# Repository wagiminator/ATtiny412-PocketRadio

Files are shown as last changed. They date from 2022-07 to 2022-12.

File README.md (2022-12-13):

# FM Pocket Radio with RDS
PocketRadio is an ATtiny402/412 controlled FM radio with RDS (RDA5807MP), an integrated audio amplifier (TC8871 or XPT8871), a LiPo battery charger (MCP73831 or TP4054), an OLED display (SSD1306) and three buttons. You can directly connect a protected 3.7V LiPo battery, a 3W / 4Ω speaker and an FM antenna.

- Project Video (YouTube): https://youtu.be/-taygMlm8Ls
- Design Files (EasyEDA): https://easyeda.com/wagiminator/attiny412-pocket-radio
- Review on Megazoid's Hut (YouTube): https://youtu.be/HVwsa0pgvS4

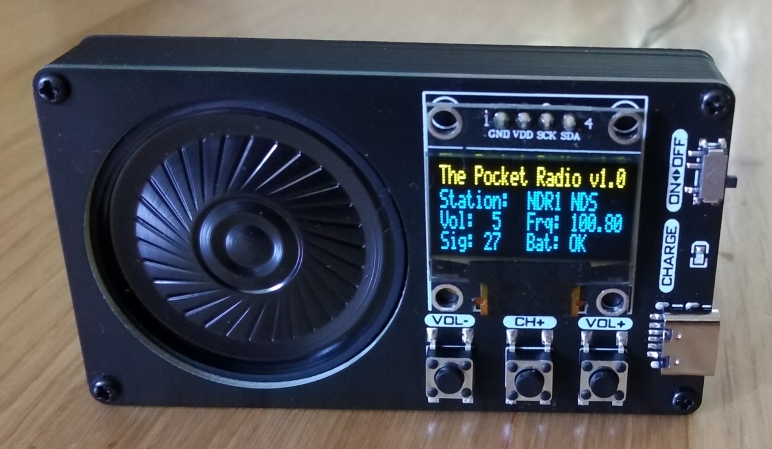
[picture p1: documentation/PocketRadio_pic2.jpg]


# Hardware
## Schematic
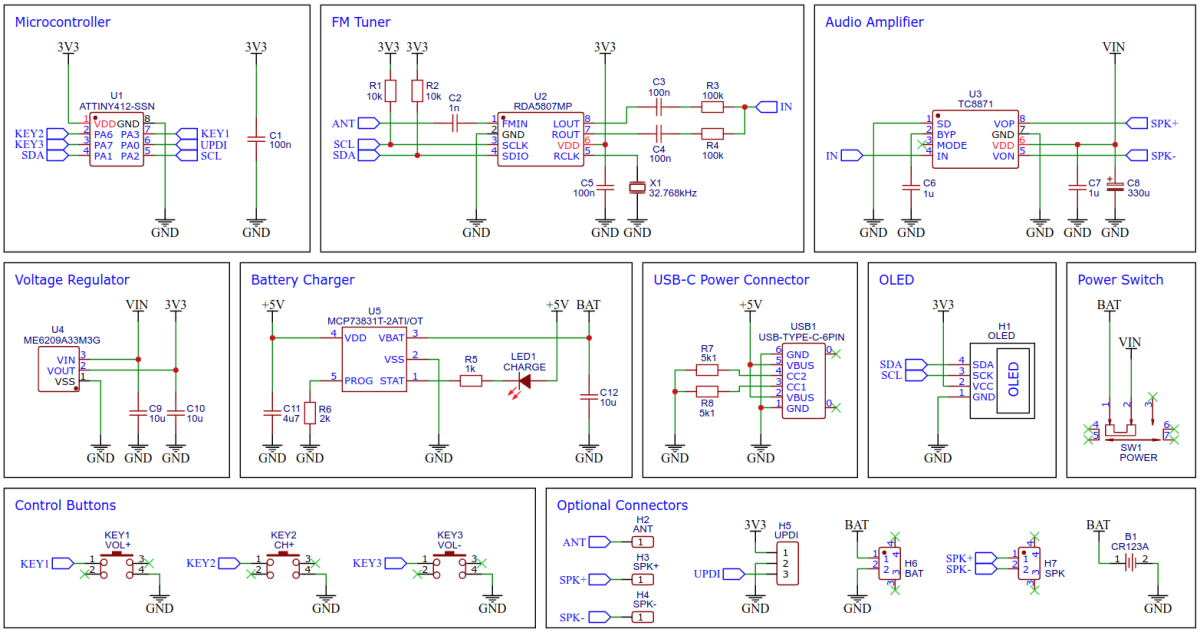
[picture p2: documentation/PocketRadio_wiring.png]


## RDA5807MP FM Radio Tuner IC
The low-cost RDA5807MP is a single-chip broadcast FM stereo radio tuner with fully integrated synthesizer, IF selectivity, RDS/RBDS and MPX decoder. The tuner uses the CMOS process, support multi-interface and require the least external component. All these make it very suitable for portable devices. The RDA5807MP is controlled by the ATtiny via I²C.

## TC8871 Audio Amplifier IC
The TC8871 is an FM-free, Class AB/Class D selectable power amplifier. When the working voltage is 5V, the maximum driving power is 5W (2Ω, BTL load, THD>10%). The application circuit of TC8871 is simple, only a few peripheral devices are needed, and the feedback resistor is integrated; the output does not need an external coupling capacitor or a power-up capacity and buffer network.
The amplification can be selected via the value of the resistors R3 and R4 (Gain = 2 * 100kΩ / (10kΩ + R3), R4 respectively), which determines the maximum volume. Keep in mind that the resistors together with the coupling capacitors C3 and C4 form a high-pass filter whose cut-off frequency is determined using the following formula: f = 1 / (2 * π * R3 * C3), R4 and C4 respectively.

## MCP73831 Li-Ion Battery Charger IC
For battery charging the MCP73831 is used. The MCP73831 is a highly advanced linear charge management controller for use in space-limited, cost-sensitive applications. It employs a constant-current/constant-voltage charge algorithm with selectable preconditioning and charge termination. The constant current value is set with one external resistor (I = 1000V / R6). Charging is done via the built-in USB-C connector. The MCP73831 can be replaced by the much cheaper TP4054.

## ME6209 Voltage Regulator
The ME6209A33 is a 3.3V positive voltage output, three–pin regulator, that provides a high current (up to 250mA) even when the input/output voltage differential is small. Low power consumption (3µA) and high accuracy (+/-2%) is achieved through CMOS technology. It allows input voltages as high as 18V with a dropout voltage around 80mV@40mA.

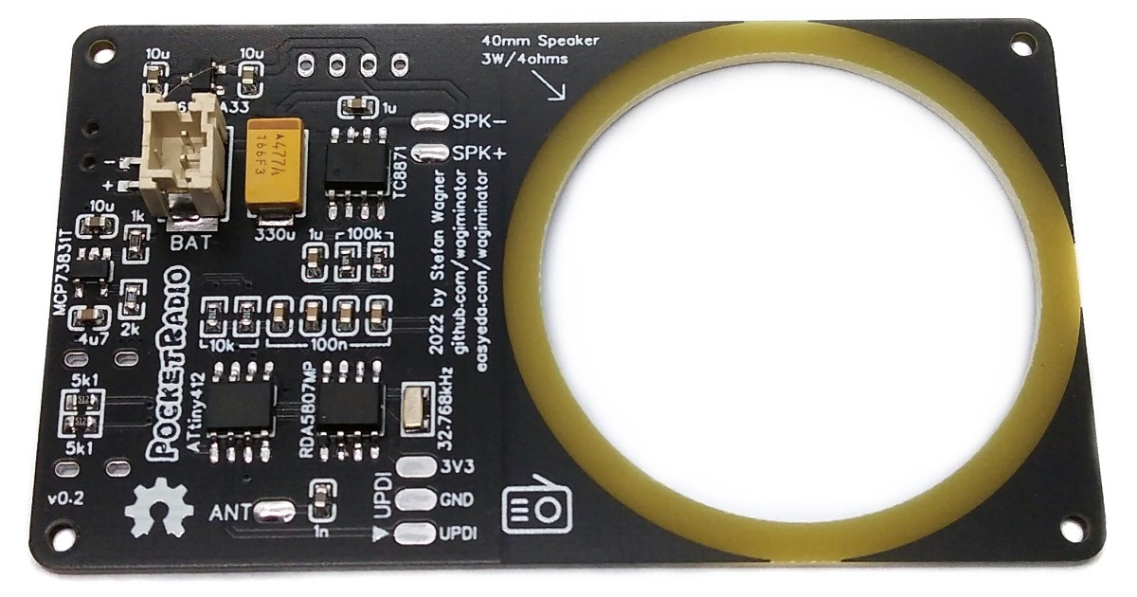
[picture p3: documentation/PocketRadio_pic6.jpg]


# Software
## Controlling the RDA5807
The FM tuner IC RDA5807MP is controlled via I²C by the ATtiny. It has six writable 16-bit registers (addresses 0x02 - 0x07) and six readable 16-bit registers (addresses 0x0A - 0x0F). The RDA5807 has two methods of write access, a sequential one in which the registers are always written starting from address 0x02 and an indexed method in which the register address is transferred first and then the content. Both methods are determined by different I²C addresses. To transfer the 16-bit register content, the high byte is sent first. The RDA5807 is controlled by setting or clearing certain bits in the respective registers. The details of the meanings of the individual registers can be found in the data sheet. The current register contents are saved in the RDA_regs arrays. The RDA implementation is based on the work of [Maarten Janssen](https://hackaday.io/project/9009-arduino-radio-with-rds).

## Compiling and Uploading the Firmware
- Connect your [UPDI programmer](https://github.com/wagiminator/AVR-Programmer) to your PC and to the UPDI header on the board. Set your programmer to work at 3.3V!
- Use one of the following methods to compile and upload the firmware:

### If using the Arduino IDE
- Open your Arduino IDE.
- Make sure you have installed [megaTinyCore](https://github.com/SpenceKonde/megaTinyCore).
- Go to **Tools -> Board -> megaTinyCore** and select **ATtiny412/402/212/202**.
- Go to **Tools** and choose the following board options:
  - **Chip:**           ATtiny402 or 412
  - **Clock:**          1 MHz internal
  - Leave the rest at the default settings.
- Go to **Tools -> Programmer** and select your UPDI programmer.
- Go to **Tools -> Burn Bootloader** to burn the fuses.
- Open the sketch and click **Upload**.

### If using the makefile (Linux/Mac)
- Make sure you have installed the latest [avr-gcc toolchain](http://maxembedded.com/2015/06/setting-up-avr-gcc-toolchain-on-linux-and-mac-os-x/).
- Open a terminal.
- Navigate to the folder with the makefile and the sketch.
- Run `DEVICE=attiny412 PROGRMR=serialupdi PORT=/dev/ttyUSB0 make install` to compile, burn the fuses and upload the firmware (change DEVICE, PROGRMR and PORT accordingly).

# Building Instructions
Solder all components to the PCB. Place the 40mm speaker in the corresponding cutout on the board. Glue the speaker in place with hot glue. Make sure that the glue is airtight all around to achieve good sound quality. Solder the connection cables between speaker and board. Solder the wire antenna to the corresponding pad on the board. A 75cm (30" = λ / 4) long 28AWG flexible silicone insulated wire works very well.

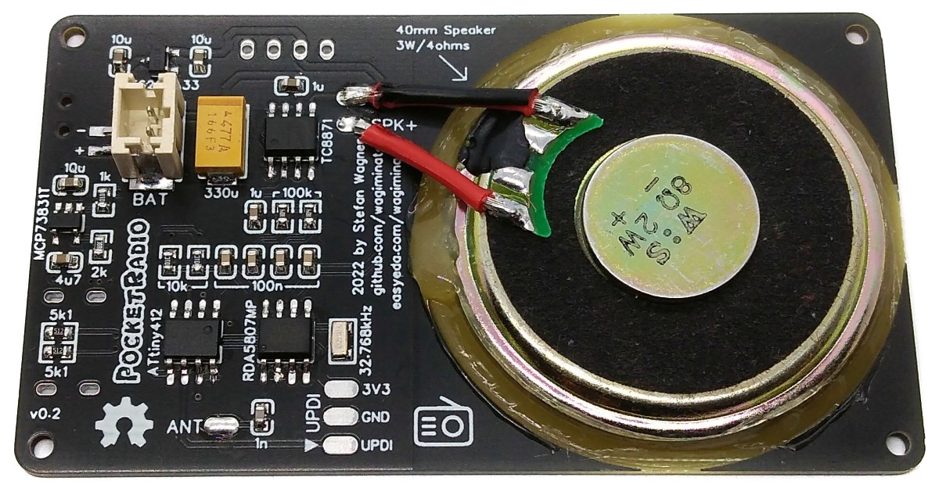
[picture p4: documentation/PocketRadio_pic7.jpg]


3D print the case. Cases with different heights are available in the "3dprint" folder. Choose the case that matches the height of your battery and speaker. Glue the battery into the case with double-sided tape. Thread the wire antenna through the small hole in the housing. To improve the sound quality, you can pack a foam mat between the battery and the PCB inside the case. This should fit snugly against the outer walls of the housing.

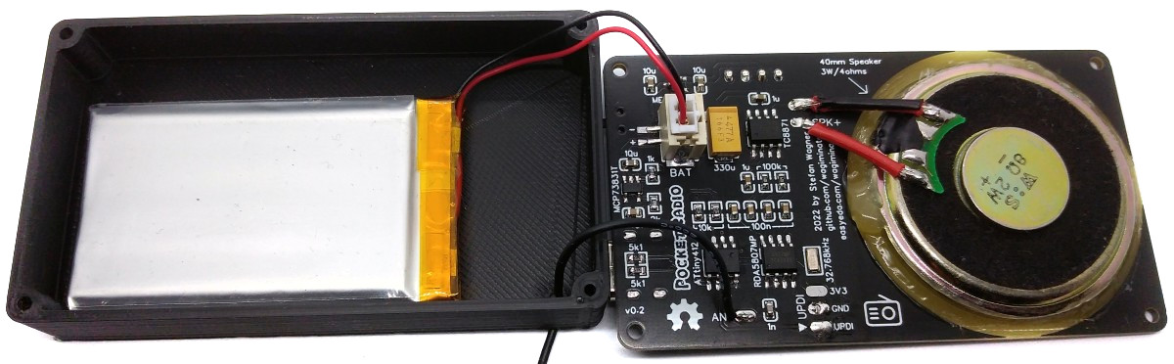
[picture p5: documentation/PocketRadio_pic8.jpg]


Connect the battery to the JST connector on the board. Pay attention to the correct polarity, unfortunately there is no standard here! At the latest now you should upload the firmware (see above). Use the UPDI pads on the board for this. Place the board on the case and screw it with four M2x5mm self-tapping screws.

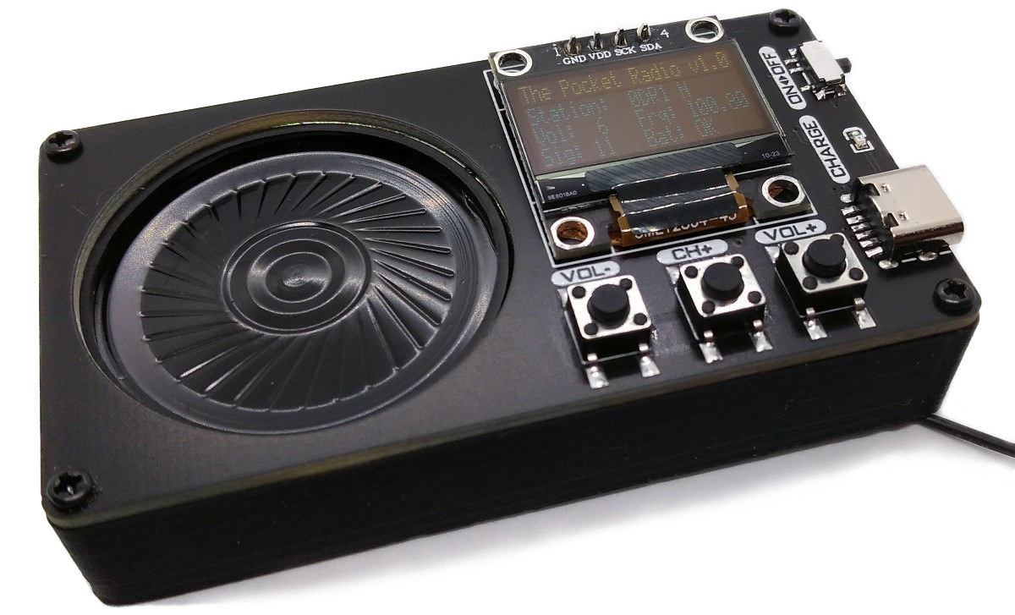
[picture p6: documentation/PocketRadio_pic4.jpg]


There are different loudspeakers with 40mm diameter. The flatter ones allow the radio to be built more compactly, while the taller ones have better sound quality.

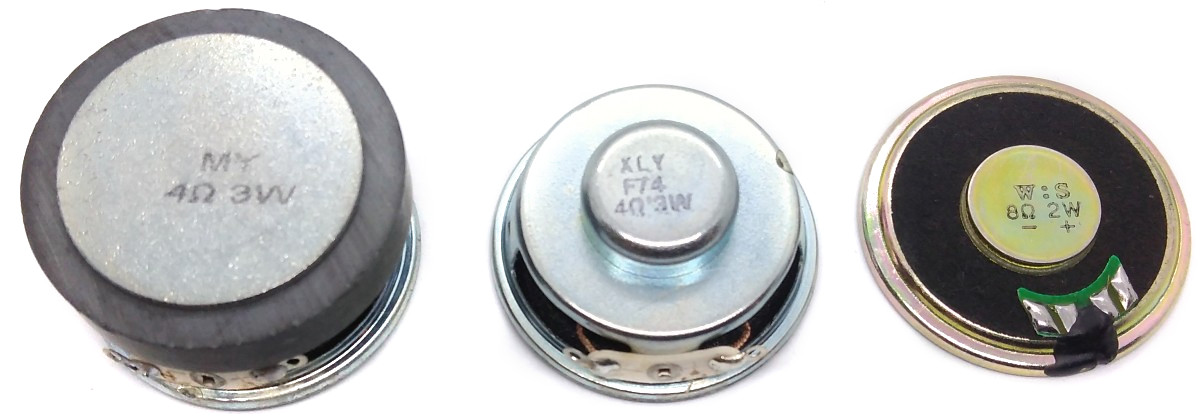
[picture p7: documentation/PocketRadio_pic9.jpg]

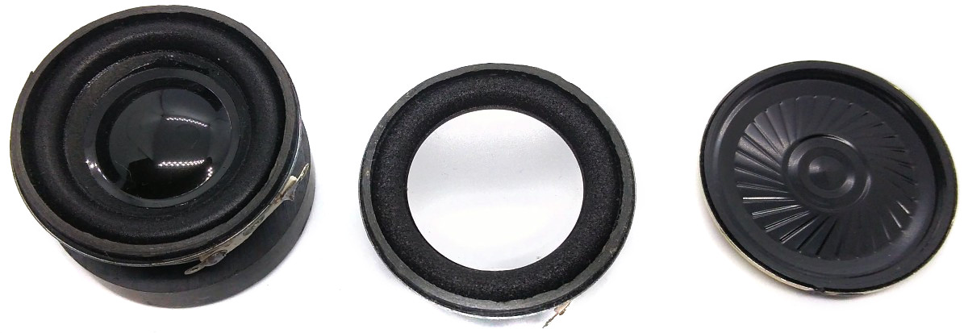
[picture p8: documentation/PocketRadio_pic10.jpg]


The size of the battery also affects the size of the radio. In operation, the radio consumes around 100mA - 125mA at 3.7V and medium volume. So a battery with a capacity of 1200mAh should provide around 10 hours of playtime.

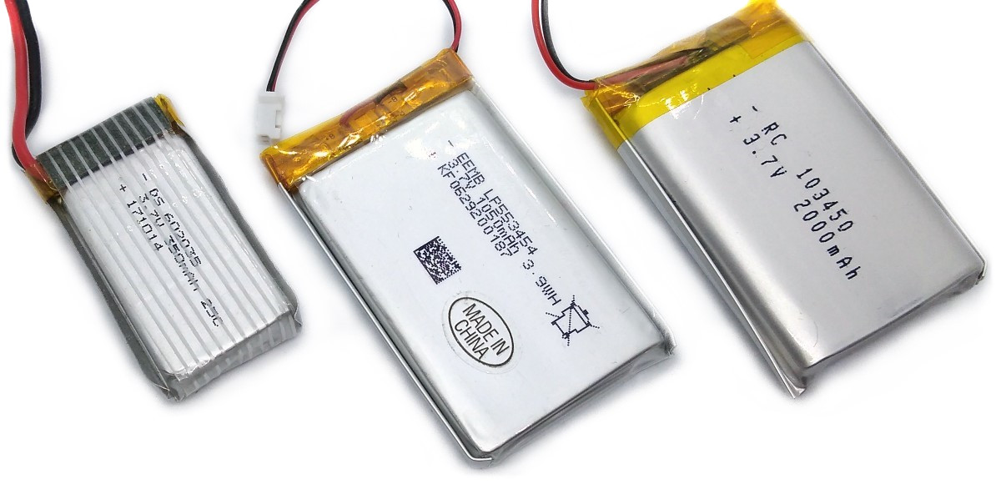
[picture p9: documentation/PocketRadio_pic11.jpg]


# Operating Instructions
1. Make sure that the wire antenna is laid as straight as possible horizontally or vertically.
2. Turn on the radio using the power switch.
3. The radio should automatically tune to the last station scanned and volume used.
4. Use the volume buttons to select the volume from 0 to 15.
5. The next station is searched for with the "CH+" button.
6. When the OLED shows "Bat: weak", you should soon recharge the battery via the USB-C port.

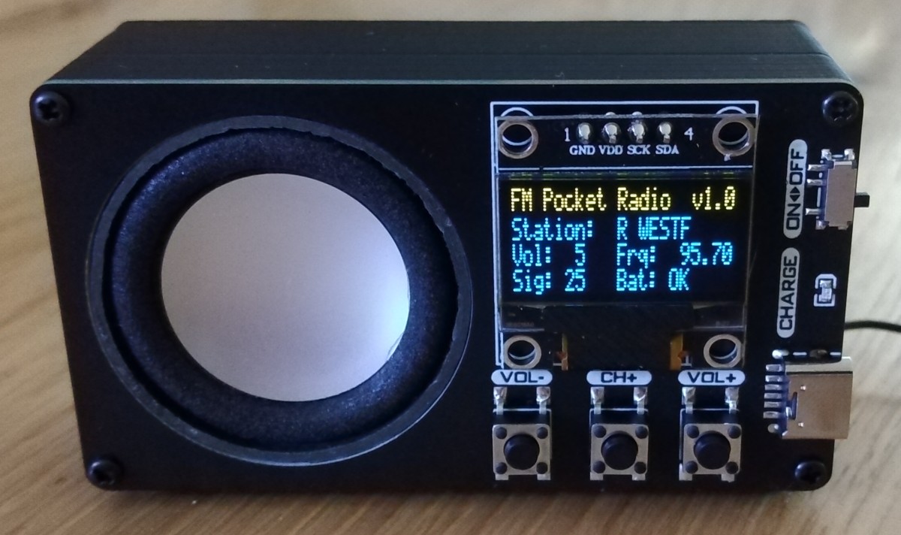
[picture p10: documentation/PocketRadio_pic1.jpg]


# References, Links and Notes
1. [ATtiny412 Datasheet](https://ww1.microchip.com/downloads/aemDocuments/documents/MCU08/ProductDocuments/DataSheets/ATtiny212-214-412-414-416-DataSheet-DS40002287A.pdf)
2. [RDA5807MP Datasheet](https://datasheet.lcsc.com/lcsc/1806121226_RDA-Microelectronics-RDA5807MP_C167245.pdf)
3. [TC8871 Datasheet](https://datasheet.lcsc.com/lcsc/2202252130_Shenzhen-Fuman-Elec-TC8871_C89482.pdf)
4. [MCP73831 Datasheet](https://datasheet.lcsc.com/lcsc/1809191822_Microchip-Tech-MCP73831T-2ATI-OT_C14879.pdf)
5. [ME6209 Datasheet](https://datasheet.lcsc.com/lcsc/1811081822_MICRONE-Nanjing-Micro-One-Elec-ME6209A33M3G_C83508.pdf)
6. [SSD1306 Datasheet](https://cdn-shop.adafruit.com/datasheets/SSD1306.pdf)
7. [ATtiny13A TinyPocketRadio](https://github.com/wagiminator/ATtiny13-TinyPocketRadio)
8. [ATtiny85 TinyFMRadio](https://github.com/wagiminator/ATtiny85-TinyFMRadio)
9. [128x64 OLED on Aliexpress](http://aliexpress.com/wholesale?SearchText=128+64+0.96+oled+new+4pin)

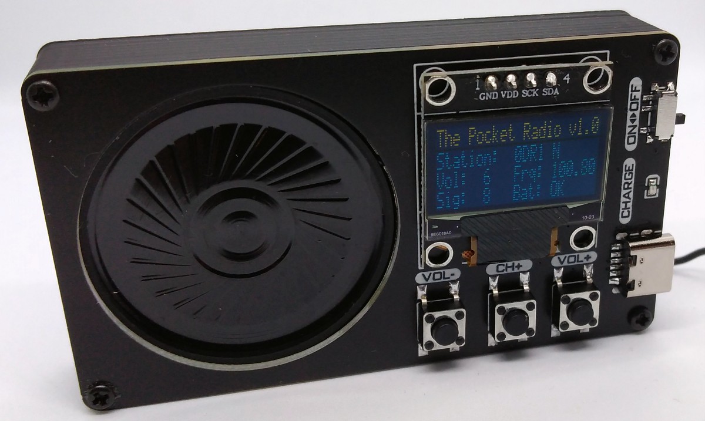
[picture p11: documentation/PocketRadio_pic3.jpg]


# License


This work is licensed under Creative Commons Attribution-ShareAlike 3.0 Unported License. 
(http://creativecommons.org/licenses/by-sa/3.0/)

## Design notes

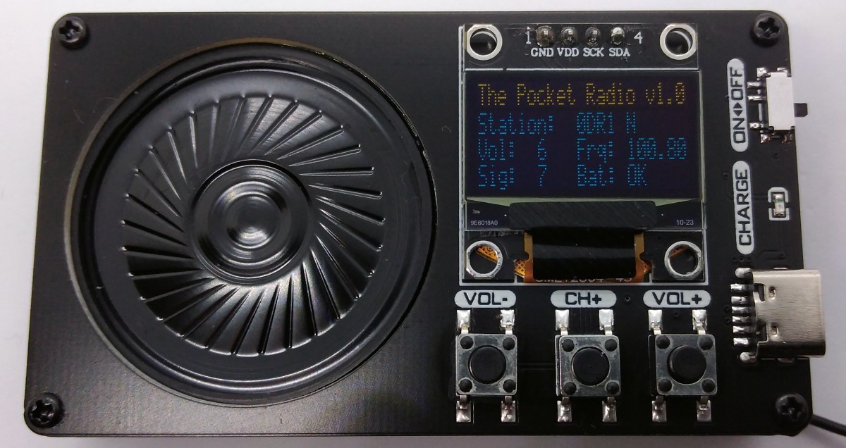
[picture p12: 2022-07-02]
documentation/PocketRadio_pic5.jpg

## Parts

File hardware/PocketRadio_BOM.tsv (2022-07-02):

ID | Name | Designator | Footprint | Quantity | Manufacturer Part | Manufacturer | Supplier | Supplier Part | Price
1 | CR123A | B1 | TH_L43.0-W-18.0-CR123A | 1 | CR123A电池座 | null | LCSC | C2803347
2 | 100n | C1,C3,C4,C5 | C_0603 | 4 | CC0603KRX7R9BB104 | YAGEO | LCSC | C14663 | 0.002
3 | 1n | C2 | C_0603 | 1 | CL10B102KB8NNNC | SAMSUNG | LCSC | C1588 | 0.003
4 | 1u | C6,C7 | C_0603 | 2 | CL10A105KB8NNNC | SAMSUNG | LCSC | C15849 | 0.005
5 | 330u | C8 | TANTALUM_CASE-D | 1 | TAJD337M010RNJ | AVX | LCSC | C105408 | 0.936
6 | 10u | C9,C10,C12 | C_0603 | 3 | CL10A106KP8NNNC | SAMSUNG | LCSC | C19702 | 0.006
7 | 4u7 | C11 | C_0603 | 1 | CL10A475KO8NNNC | SAMSUNG | LCSC | C19666 | 0.01
8 | OLED | H1 | I2C OLED 0.96 NEW | 1 | SSD1306 I2C OLED
9 | ANT | H2 | PAD_1 | 1 |  |  | LCSC | C81276 | 0.007
10 | SPK+ | H3 | PAD_1 | 1 |  |  | LCSC | C81276 | 0.007
11 | SPK- | H4 | PAD_1 | 1 |  |  | LCSC | C81276 | 0.007
12 | UPDI | H5 | PAD_3 | 1 | Header2.54mm 1*3P | BOOMELE | LCSC | C49257 | 0.014
13 | BAT | H6 | CONN-SMD_2P_PH2.0_LT | 1 | PH2.0-2P | BOOMELE | LCSC | C64658 | 0.064
14 | SPK | H7 | CONN-SMD_2P_PH2.0_LT | 1 | PH2.0-2P | BOOMELE | LCSC | C64658 | 0.064
15 | VOL+ | KEY1 | KEY-6.0*6.0 | 1 | SMD Tactile Switch6*6*6mm | ReliaPro | LCSC | C23873 | 0.018
16 | CH+ | KEY2 | KEY-6.0*6.0 | 1 | SMD Tactile Switch6*6*6mm | ReliaPro | LCSC | C23873 | 0.018
17 | VOL- | KEY3 | KEY-6.0*6.0 | 1 | SMD Tactile Switch6*6*6mm | ReliaPro | LCSC | C23873 | 0.018
18 | CHARGE | LED1 | LED_0603 | 1 | KT-0603R | KENTO | LCSC | C2286
19 | 10k | R1,R2 | 0603 | 2 | 0603WAF1002T5E | UniOhm | LCSC | C25804 | 0.001
20 | 100k | R3,R4 | 0603 | 2 | 0603WAF1003T5E | UniOhm | LCSC | C25803 | 0.001
21 | 1k | R5 | 0603 | 1 | 0603WAF1001T5E | UniOhm | LCSC | C21190 | 0.001
22 | 2k | R6 | 0603 | 1 | 0603WAF2001T5E | UniOhm | LCSC | C22975 | 0.001
23 | 5k1 | R7,R8 | 0603 | 2 | 0603WAF5101T5E | UniOhm | LCSC | C23186 | 0.001
24 | POWER | SW1 | SW-SMD_SS-1290L-GLL-1.5MM | 1 | SS-1290L-GL L=1.5mm | RI SHENG | LCSC | C695418 | 0.12
25 | ATTINY412-SSN | U1 | SOP-8_150MIL | 1 | ATTINY412-SSN | MICROCHIP(美国微芯) | LCSC | C1338223 | 0.577
26 | RDA5807MP | U2 | SOP-8_150MIL | 1 | RDA5807MP | RDA Microelectronics | LCSC | C167245 | 0.158
27 | TC8871 | U3 | SOP-8_EP_150MIL | 1 | TC8871 | FM | LCSC | C89482 | 0.153
28 | ME6209A33M3G | U4 | SOT-23-3_W | 1 | ME6209A33M3G | MICRONE | LCSC | C83508 | 0.072
29 | MCP73831T-2ATI/OT | U5 | SOT-23-5_BR | 1 | MCP73831T-2ATI/OT | MICROCHIP | LCSC | C14879 | 1.846
30 | USB-TYPE-C-6PIN | USB1 | USB-C-SMD-6P | 1 | TYPE-C-31-M-17 | Korean Hroparts Elec | LCSC | C283540 | 0.204
31 | 32.768kHz | X1 | OSC-SMD_3215 | 1 | AH03270014 | TXC Corp | LCSC | C409356

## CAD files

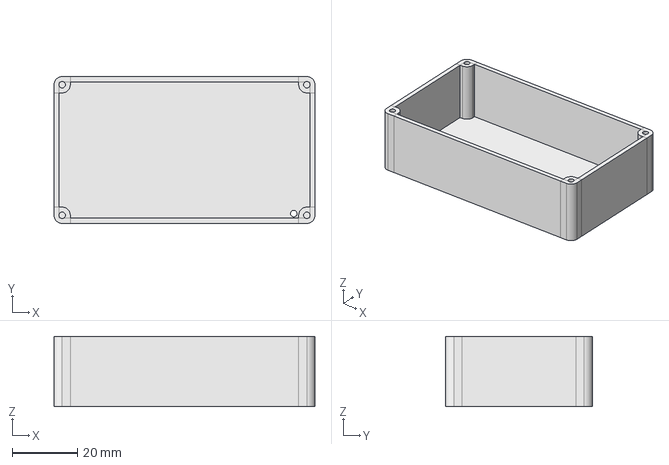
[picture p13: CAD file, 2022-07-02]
3dprint/PocketRadio_case_20mm.fcstd
80.0 x 45.0 x 21.6 mm

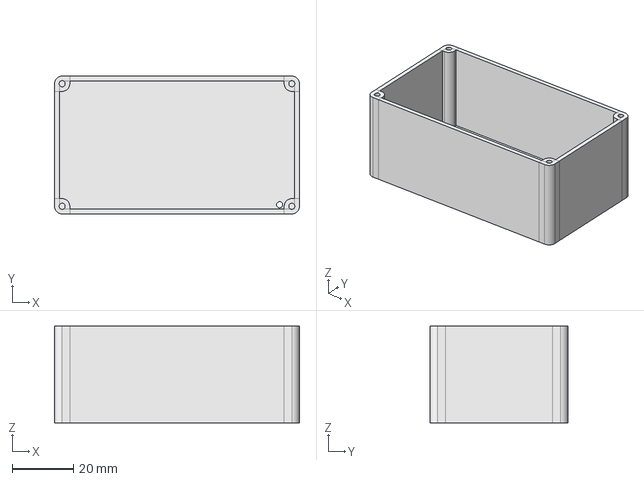
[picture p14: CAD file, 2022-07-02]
3dprint/PocketRadio_case_30mm.fcstd
80.0 x 45.0 x 31.6 mm

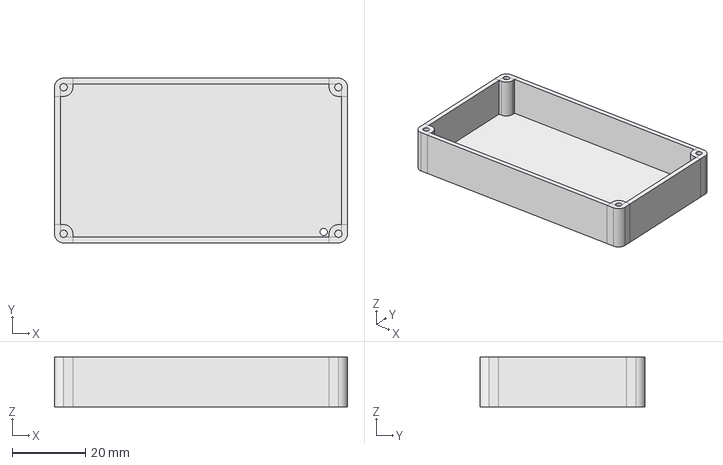
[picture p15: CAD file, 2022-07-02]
3dprint/PocketRadio_case_12mm.fcstd
80.0 x 45.0 x 13.6 mm

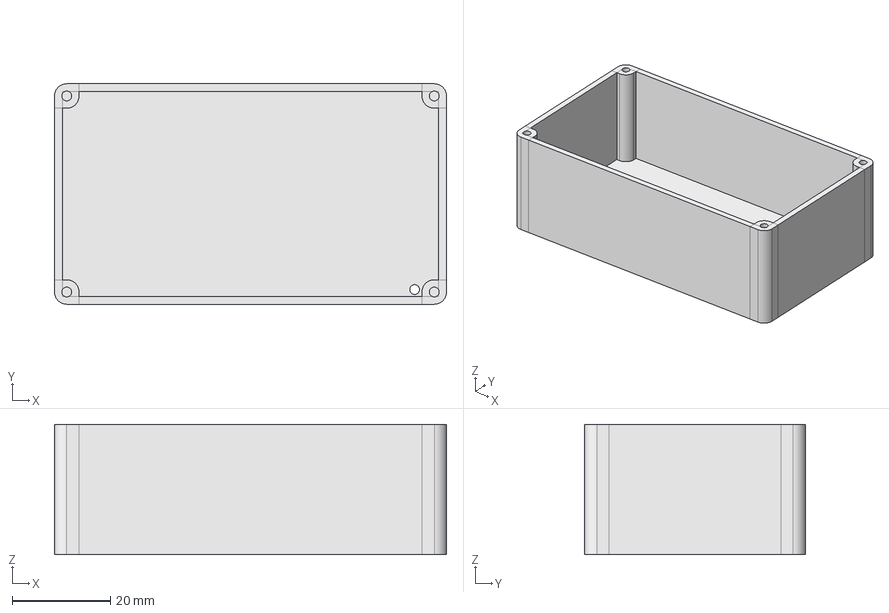
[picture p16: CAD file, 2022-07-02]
3dprint/PocketRadio_case_25mm.fcstd
80.0 x 45.0 x 26.6 mm

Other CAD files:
3dprint/PocketRadio_case_12mm.stl
3dprint/PocketRadio_case_20mm.stl
3dprint/PocketRadio_case_25mm.stl
3dprint/PocketRadio_case_30mm.stl

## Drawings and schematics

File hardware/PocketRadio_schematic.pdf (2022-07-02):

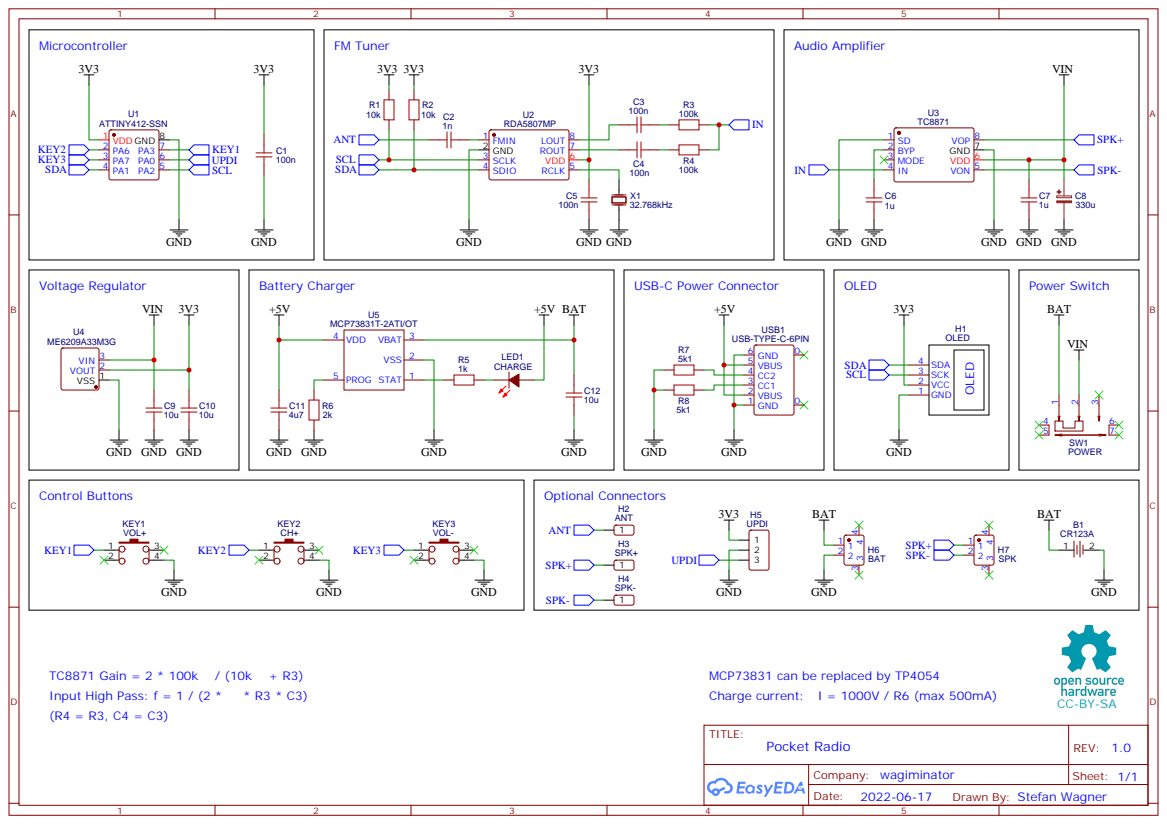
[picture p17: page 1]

Drawn By: Stefan Wagner

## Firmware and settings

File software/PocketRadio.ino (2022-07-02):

// ===================================================================================
// Project:   PocketRadio - FM Tuner with RDS based on ATtiny402/412 and RDA5807MP
// Version:   v1.0
// Year:      2022
// Author:    Stefan Wagner
// Github:    https://github.com/wagiminator
// EasyEDA:   https://easyeda.com/wagiminator
// License:   http://creativecommons.org/licenses/by-sa/3.0/
// ===================================================================================
//
// Description:
// ------------
// This firmware implements the basic functionality of the Pocket Radio. By pressing
// the CH+ button the RDA5807 seeks the next radio station, presseng the VOL+/VOL-
// button increases/decreases the volume. The selected frequency and volume are
// stored in the EEPROM. Station name, frequency, signal strength, volume and battery
// state of charge are shown on an OLED display.
//
// References:
// -----------
// RDA5807 datasheet:
// https://datasheet.lcsc.com/szlcsc/1806121226_RDA-Microelectronics-RDA5807MP_C167245.pdf
//
// SSD1306 OLED datasheet:
// https://cdn-shop.adafruit.com/datasheets/SSD1306.pdf
//
// The implementation is based on the ATtiny85-version (TinyFMRadio):
// https://github.com/wagiminator/ATtiny85-TinyFMRadio
//
// The OLED font was adapted from Neven Boyanov and Stephen Denne:
// https://github.com/datacute/Tiny4kOLED
//
// The RDA8507 implementation was adapted from Maarten Janssen:
// https://hackaday.io/project/9009-arduino-radio-with-rds
//
// Wiring:
// -------
//                           +-\/-+
//                     Vdd  1|°   |8  GND
//  CH+ button --- TXD PA6  2|    |7  PA3 AIN3 -------- VOL+ button
// VOL- button --- RXD PA7  3|    |6  PA0 AIN0 UPDI --- UPDI
//     I2C SDA --- SDA PA1  4|    |5  PA2 AIN2 SCL ---- I2C SCL
//                           +----+
//
// Compilation Settings:
// ---------------------
// Core:    megaTinyCore (https://github.com/SpenceKonde/megaTinyCore)
// Board:   ATtiny412/402/212/202
// Chip:    ATtiny402 or ATtiny412
// Clock:   1 MHz internal
//
// Leave the rest on default settings. Use a programmer that works with 3.3V.
// Don't forget to "Burn bootloader". Compile and upload the code.
//
// No Arduino core functions or libraries are used. To compile and upload without
// Arduino IDE download AVR 8-bit toolchain at:
// https://www.microchip.com/mplab/avr-support/avr-and-arm-toolchains-c-compilers
// and extract to tools/avr-gcc. Use the makefile to compile and upload.
//
// Fuse Settings: 0:0x00 1:0x00 2:0x01 4:0x00 5:0xC5 6:0x04 7:0x00 8:0x00


// ===================================================================================
// Libraries, Definitions and Macros
// ===================================================================================

// Libraries
#include <avr/io.h>                 // for GPIO
#include <avr/eeprom.h>             // for storing user settings into EEPROM
#include <util/delay.h>             // for delays

// Pin assignments
#define PIN_SDA       PA1           // I2C Serial Data,  connect to OLED/RDA
#define PIN_SCL       PA2           // I2C Serial Clock, connect to OLED/RDA
#define PIN_VOL_UP    PA3           // VOL+ button
#define PIN_CH_UP     PA6           // CH+  button
#define PIN_VOL_DOWN  PA7           // VOL- button

// Firmware parameters
#define EEPROM_IDENT  0x6CE7        // to identify if EEPROM was written by this program
#define OLED_CONTRAST 96            // 0 .. 255    brightness of OLED 
#define HEADER        "FM Pocket Radio  v1.0"   // text on top of the screen

// Variables
uint16_t  channel;                  // 0 .. 1023   current channel
uint8_t   volume = 5;               // 0 .. 15     current volume

// Pin manipulation macros
enum {PA0, PA1, PA2, PA3, PA4, PA5, PA6, PA7};      // enumerate pin designators
#define pinInput(x)       VPORTA.DIR &= ~(1<<(x))   // set pin to INPUT
#define pinOutput(x)      VPORTA.DIR |=  (1<<(x))   // set pin to OUTPUT
#define pinLow(x)         VPORTA.OUT &= ~(1<<(x))   // set pin to LOW
#define pinHigh(x)        VPORTA.OUT |=  (1<<(x))   // set pin to HIGH
#define pinToggle(x)      VPORTA.IN  |=  (1<<(x))   // TOGGLE pin
#define pinRead(x)        (VPORTA.IN &   (1<<(x)))  // READ pin
#define pinPullup(x)      (&PORTA.PIN0CTRL)[x] |= PORT_PULLUPEN_bm  // enable pullup

// ===================================================================================
// I2C Master Implementation (Software Bit-Banging)
// ===================================================================================

// I2C macros
#define I2C_SDA_HIGH()  pinInput(PIN_SDA)       // release SDA   -> pulled HIGH by resistor
#define I2C_SDA_LOW()   pinOutput(PIN_SDA)      // SDA as output -> pulled LOW  by MCU
#define I2C_SCL_HIGH()  pinInput(PIN_SCL)       // release SCL   -> pulled HIGH by resistor
#define I2C_SCL_LOW()   pinOutput(PIN_SCL)      // SCL as output -> pulled LOW  by MCU
#define I2C_SDA_READ()  pinRead(PIN_SDA)        // read SDA line
#define I2C_CLOCKOUT()  I2C_SCL_HIGH();I2C_SCL_LOW()  // clock out

// I2C transmit one data byte to the slave, ignore ACK bit, no clock stretching allowed
void I2C_write(uint8_t data) {
  for(uint8_t i=8; i; i--, data<<=1) {          // transmit 8 bits, MSB first
    (data&0x80)?I2C_SDA_HIGH():I2C_SDA_LOW();   // SDA depending on bit
    I2C_CLOCKOUT();                             // clock out -> slave reads the bit
  }
  I2C_SDA_HIGH();                               // release SDA for ACK bit of slave
  I2C_CLOCKOUT();                               // 9th clock pulse is for the ignored ACK bit
}

// I2C start transmission
void I2C_start(uint8_t addr) {
  I2C_SDA_LOW();                                // start condition: SDA goes LOW first
  I2C_SCL_LOW();                                // start condition: SCL goes LOW second
  I2C_write(addr);                              // send slave address
}

// I2C restart transmission
void I2C_restart(uint8_t addr) {
  I2C_SDA_HIGH();                               // prepare SDA for HIGH to LOW transition
  I2C_SCL_HIGH();                               // restart condition: clock HIGH
  I2C_start(addr);                              // start again
}

// I2C stop transmission
void I2C_stop(void) {
  I2C_SDA_LOW();                                // prepare SDA for LOW to HIGH transition
  I2C_SCL_HIGH();                               // stop condition: SCL goes HIGH first
  I2C_SDA_HIGH();                               // stop condition: SDA goes HIGH second
}

// I2C receive one data byte from the slave (ack=0 for last byte, ack>0 if more bytes to follow)
uint8_t I2C_read(uint8_t ack) {
  uint8_t data = 0;                             // variable for the received byte
  I2C_SDA_HIGH();                               // release SDA -> will be toggled by slave
  for(uint8_t i=8; i; i--) {                    // receive 8 bits
    data <<= 1;                                 // bits shifted in right (MSB first)
    I2C_SCL_HIGH();                             // clock HIGH
    if(I2C_SDA_READ()) data |= 1;               // read bit
    I2C_SCL_LOW();                              // clock LOW -> slave prepares next bit
  }
  if(ack) I2C_SDA_LOW();                        // pull SDA LOW to acknowledge (ACK)
  I2C_CLOCKOUT();                               // clock out -> slave reads ACK bit
  return data;                                  // return the received byte
}

// ===================================================================================
// OLED Implementation
// ===================================================================================

// OLED definitions
#define OLED_ADDR       0x78                      // OLED write address
#define OLED_CMD_MODE   0x00                      // set command mode
#define OLED_DAT_MODE   0x40                      // set data modearray

// OLED init settings
const uint8_t OLED_INIT_CMD[] = {
  0xC8, 0xA1,                                     // flip screen
  0xA8, 0x1F,                                     // set multiplex ratio
  0xDA, 0x02,                                     // set com pins hardware configuration
  0x8D, 0x14,                                     // set DC-DC enable
  0xAF,                                           // display on
  0x81, OLED_CONTRAST                             // set brightness
};

// Standard ASCII 5x8 font (adapted from Neven Boyanov and Stephen Denne)
const uint8_t OLED_FONT[] = {
  0x00, 0x00, 0x00, 0x00, 0x00, 0x00, 0x00, 0x2F, 0x00, 0x00, 0x00, 0x07, 0x00, 0x07, 0x00,
  0x14, 0x7F, 0x14, 0x7F, 0x14, 0x24, 0x2A, 0x7F, 0x2A, 0x12, 0x23, 0x13, 0x08, 0x64, 0x62,
  0x36, 0x49, 0x55, 0x22, 0x50, 0x00, 0x05, 0x03, 0x00, 0x00, 0x00, 0x1C, 0x22, 0x41, 0x00,
  0x00, 0x41, 0x22, 0x1C, 0x00, 0x14, 0x08, 0x3E, 0x08, 0x14, 0x08, 0x08, 0x3E, 0x08, 0x08,
  0x00, 0x00, 0xA0, 0x60, 0x00, 0x08, 0x08, 0x08, 0x08, 0x08, 0x00, 0x60, 0x60, 0x00, 0x00,
  0x20, 0x10, 0x08, 0x04, 0x02, 0x3E, 0x51, 0x49, 0x45, 0x3E, 0x00, 0x42, 0x7F, 0x40, 0x00,
  0x42, 0x61, 0x51, 0x49, 0x46, 0x21, 0x41, 0x45, 0x4B, 0x31, 0x18, 0x14, 0x12, 0x7F, 0x10,
  0x27, 0x45, 0x45, 0x45, 0x39, 0x3C, 0x4A, 0x49, 0x49, 0x30, 0x01, 0x71, 0x09, 0x05, 0x03,
  0x36, 0x49, 0x49, 0x49, 0x36, 0x06, 0x49, 0x49, 0x29, 0x1E, 0x00, 0x36, 0x36, 0x00, 0x00,
  0x00, 0x56, 0x36, 0x00, 0x00, 0x08, 0x14, 0x22, 0x41, 0x00, 0x14, 0x14, 0x14, 0x14, 0x14,
  0x00, 0x41, 0x22, 0x14, 0x08, 0x02, 0x01, 0x51, 0x09, 0x06, 0x32, 0x49, 0x59, 0x51, 0x3E,
  0x7C, 0x12, 0x11, 0x12, 0x7C, 0x7F, 0x49, 0x49, 0x49, 0x36, 0x3E, 0x41, 0x41, 0x41, 0x22,
  0x7F, 0x41, 0x41, 0x22, 0x1C, 0x7F, 0x49, 0x49, 0x49, 0x41, 0x7F, 0x09, 0x09, 0x09, 0x01,
  0x3E, 0x41, 0x49, 0x49, 0x7A, 0x7F, 0x08, 0x08, 0x08, 0x7F, 0x00, 0x41, 0x7F, 0x41, 0x00,
  0x20, 0x40, 0x41, 0x3F, 0x01, 0x7F, 0x08, 0x14, 0x22, 0x41, 0x7F, 0x40, 0x40, 0x40, 0x40,
  0x7F, 0x02, 0x0C, 0x02, 0x7F, 0x7F, 0x04, 0x08, 0x10, 0x7F, 0x3E, 0x41, 0x41, 0x41, 0x3E,
  0x7F, 0x09, 0x09, 0x09, 0x06, 0x3E, 0x41, 0x51, 0x21, 0x5E, 0x7F, 0x09, 0x19, 0x29, 0x46,
  0x46, 0x49, 0x49, 0x49, 0x31, 0x01, 0x01, 0x7F, 0x01, 0x01, 0x3F, 0x40, 0x40, 0x40, 0x3F,
  0x1F, 0x20, 0x40, 0x20, 0x1F, 0x3F, 0x40, 0x38, 0x40, 0x3F, 0x63, 0x14, 0x08, 0x14, 0x63,
  0x07, 0x08, 0x70, 0x08, 0x07, 0x61, 0x51, 0x49, 0x45, 0x43, 0x00, 0x7F, 0x41, 0x41, 0x00,
  0x02, 0x04, 0x08, 0x10, 0x20, 0x00, 0x41, 0x41, 0x7F, 0x00, 0x04, 0x02, 0x01, 0x02, 0x04,
  0x40, 0x40, 0x40, 0x40, 0x40, 0x00, 0x01, 0x02, 0x04, 0x00, 0x20, 0x54, 0x54, 0x54, 0x78,
  0x7F, 0x48, 0x44, 0x44, 0x38, 0x38, 0x44, 0x44, 0x44, 0x20, 0x38, 0x44, 0x44, 0x48, 0x7F,
  0x38, 0x54, 0x54, 0x54, 0x18, 0x08, 0x7E, 0x09, 0x01, 0x02, 0x18, 0xA4, 0xA4, 0xA4, 0x7C,
  0x7F, 0x08, 0x04, 0x04, 0x78, 0x00, 0x44, 0x7D, 0x40, 0x00, 0x40, 0x80, 0x84, 0x7D, 0x00,
  0x7F, 0x10, 0x28, 0x44, 0x00, 0x00, 0x41, 0x7F, 0x40, 0x00, 0x7C, 0x04, 0x18, 0x04, 0x78,
  0x7C, 0x08, 0x04, 0x04, 0x78, 0x38, 0x44, 0x44, 0x44, 0x38, 0xFC, 0x24, 0x24, 0x24, 0x18,
  0x18, 0x24, 0x24, 0x18, 0xFC, 0x7C, 0x08, 0x04, 0x04, 0x08, 0x48, 0x54, 0x54, 0x54, 0x20,
  0x04, 0x3F, 0x44, 0x40, 0x20, 0x3C, 0x40, 0x40, 0x20, 0x7C, 0x1C, 0x20, 0x40, 0x20, 0x1C,
  0x3C, 0x40, 0x30, 0x40, 0x3C, 0x44, 0x28, 0x10, 0x28, 0x44, 0x1C, 0xA0, 0xA0, 0xA0, 0x7C,
  0x44, 0x64, 0x54, 0x4C, 0x44, 0x08, 0x36, 0x41, 0x41, 0x00, 0x00, 0x00, 0x7F, 0x00, 0x00,
  0x00, 0x41, 0x41, 0x36, 0x08, 0x08, 0x04, 0x08, 0x10, 0x08, 0xFF, 0xFF, 0xFF, 0xFF, 0xFF
};

// OLED variables
uint8_t OLED_x, OLED_y;                           // current cursor position
const uint16_t DIVIDER[] = {1, 10, 100, 1000, 10000};
//const uint16_t DIVIDER[] = {10000, 1000, 100, 10, 1}; // BCD conversion array

// OLED init function
void OLED_init(void) {
  I2C_start(OLED_ADDR);                           // start transmission to OLED
  I2C_write(OLED_CMD_MODE);                       // set command mode
  for (uint8_t i = 0; i < sizeof(OLED_INIT_CMD); i++)
    I2C_write(OLED_INIT_CMD[i]);                  // send the command bytes
  I2C_stop();                                     // stop transmission
}

// OLED set the cursor
void OLED_setCursor(uint8_t xpos, uint8_t ypos) {
  xpos &= 0x7F; ypos &= 0x03;                     // limit cursor position values
  I2C_start(OLED_ADDR);                           // start transmission to OLED
  I2C_write(OLED_CMD_MODE);                       // set command mode
  I2C_write(xpos & 0x0F);                         // set low nibble of start column
  I2C_write(0x10 | (xpos >> 4));                  // set high nibble of start column
  I2C_write(0xB0 |  ypos);                        // set start page
  I2C_stop();                                     // stop transmission
  OLED_x = xpos; OLED_y = ypos;                   // set the cursor variables
}

// OLED clear rest of the current line
void OLED_clearLine(void) {
  I2C_start(OLED_ADDR);                           // start transmission to OLED
  I2C_write(OLED_DAT_MODE);                       // set data mode
  while(OLED_x++ < 128) I2C_write(0);             // clear rest of the line
  I2C_stop();                                     // stop transmission
  OLED_setCursor(0, ++OLED_y);                    // set cursor to start of next line
}

// OLED clear screen
void OLED_clearScreen(void) {
  OLED_setCursor(0, 0);                           // set cursor to home position
  for(uint8_t i=4; i; i--) OLED_clearLine();      // clear all 4 lines
}

// OLED plot a single character
void OLED_plotChar(char c) {
  uint16_t ptr = c - 32;                          // character pointer
  ptr += ptr << 2;                                // -> ptr = (ch - 32) * 5;
  I2C_write(0x00);                                // write space between characters
  for (uint8_t i=5 ; i; i--) I2C_write(OLED_FONT[ptr++]);
  OLED_x += 6;                                    // update cursor
  if (OLED_x > 122) {                             // line end ?
    I2C_stop();                                   // stop data transmission
    OLED_setCursor(0,++OLED_y);                   // set next line start
    I2C_start(OLED_ADDR);                         // start transmission to OLED
    I2C_write(OLED_DAT_MODE);                     // set data mode
  }
}

// OLED print a string
void OLED_print(const char* str) {
  I2C_start(OLED_ADDR);                           // start transmission to OLED
  I2C_write(OLED_DAT_MODE);                       // set data mode
  while(*str) OLED_plotChar(*str++);              // plot each character
  I2C_stop();                                     // stop transmission
}

// OLED print a string with new line
void OLED_println(const char* str) {
  OLED_print(str);                                // print the string
  OLED_clearLine();                               // clear rest of the line
}

// OLED print value (BCD conversion by substraction method)
void OLED_printVal(uint16_t value, uint8_t digits, uint8_t decimal) {
  uint8_t leadflag = 0;                           // flag for leading spaces
  I2C_start(OLED_ADDR);                           // start transmission to OLED
  I2C_write(OLED_DAT_MODE);                       // set data mode
  while(digits--) {                               // for all digits digits
    uint8_t digitval = 0;                         // start with digit value 0
    uint16_t divider = DIVIDER[digits];           // read current divider
    while(value >= divider) {                     // if current divider fits into the value
      leadflag = 1;                               // end of leading spaces
      digitval++;                                 // increase digit value
      value -= divider;                           // decrease value by divider
    }
    if(digits == decimal) leadflag++;             // end leading spaces before decimal
    if(leadflag) OLED_plotChar(digitval + '0');   // print the digit
    else         OLED_plotChar(' ');              // or print leading space
    if(decimal && (digits == decimal)) OLED_plotChar('.');  // print decimal
  }
  I2C_stop();                                     // stop transmission
}

// ===================================================================================
// RDA5807 Implementation
// ===================================================================================

// RDA definitions
#define RDA_ADDR_SEQ    0x20                      // RDA I2C write address for sequential access
#define RDA_ADDR_INDEX  0x22                      // RDA I2C write address for indexed access
#define RDA_VOL         1                         // start volume

// RDA register definitions
enum{ RDA_REG_2, RDA_REG_3, RDA_REG_4, RDA_REG_5, RDA_REG_6, RDA_REG_7 };
enum{ RDA_REG_A, RDA_REG_B, RDA_REG_C, RDA_REG_D, RDA_REG_E, RDA_REG_F };
uint16_t RDA_read_regs[6];                        // RDA registers for reading
uint16_t RDA_write_regs[6] = {                    // RDA registers for writing:
  0b1101001000001101,                             // RDA register 0x02 preset
  0b0001010111000000,                             // RDA register 0x03 preset
  0b0000101000000000,                             // RDA register 0x04 preset
  0b1000100010000000,                             // RDA register 0x05 preset
  0b0000000000000000,                             // RDA register 0x06 preset
  0b0000000000000000                              // RDA register 0x07 preset
};

// RDA state macros
#define RDA_hasRdsData        ( RDA_read_regs[RDA_REG_A] & 0x8000 )
#define RDA_isTuning          (~RDA_read_regs[RDA_REG_A] & 0x4000 )
#define RDA_tuningError       ( RDA_read_regs[RDA_REG_A] & 0x2000 )
#define RDA_hasRdsBlockE      ( RDA_read_regs[RDA_REG_A] & 0x0800 )
#define RDA_isStereo          ( RDA_read_regs[RDA_REG_A] & 0x0400 )
#define RDA_channel           ( RDA_read_regs[RDA_REG_A] & 0x03FF )
#define RDA_isTunedToChannel  ( RDA_read_regs[RDA_REG_B] & 0x0100 )
#define RDA_rdsBlockE         ( RDA_read_regs[RDA_REG_B] & 0x0010 )
#define RDA_rdsBlockErrors    ( RDA_read_regs[RDA_REG_B] & 0x000F )
#define RDA_signalStrength    ((RDA_read_regs[RDA_REG_B] & 0xFE00 ) >> 9 )

// RDA variables
char RDA_stationName[9];                          // string for the station name
char RDA_rdsStationName[8];                       // just for internal use

// RDA write specified register
void RDA_writeReg(uint8_t reg) {
  I2C_start(RDA_ADDR_INDEX);                      // start I2C for index write to RDA
  I2C_write(0x02 + reg);                          // set the register to write
  I2C_write(RDA_write_regs[reg] >> 8);            // send high byte
  I2C_write(RDA_write_regs[reg]);                 // send low byte
  I2C_stop();                                     // stop I2C
}

// RDA write all registers
void RDA_writeAllRegs(void) {
  I2C_start(RDA_ADDR_SEQ);                        // start I2C for sequential write to RDA
  for(uint8_t i=0; i<6; i++) {                    // write to 6 registers
    I2C_write(RDA_write_regs[i] >> 8);            // send high byte
    I2C_write(RDA_write_regs[i]);                 // send low byte
  }
  I2C_stop();                                     // stop I2C
}

// RDA read all registers
void RDA_readAllRegs(void) {
  I2C_start(RDA_ADDR_SEQ | 1);                    // start I2C for sequential read from RDA
  for(uint8_t i=0; i<6; i++)                      // read 6 registers
    RDA_read_regs[i] = (uint16_t)(I2C_read(1) << 8) | I2C_read(5-i);
  I2C_stop();                                     // stop I2C
}

// RDA clear station
void RDA_resetStation(void) {
  for(uint8_t i=0; i<8; i++) RDA_stationName[i] = ' ';
}

// RDA initialize tuner
void RDA_init(void) {
  RDA_resetStation();                             // reset station available
  RDA_stationName[8] = 0;                         // set string terminator
  RDA_write_regs[RDA_REG_2] |=  0x0002;           // set soft reset
  RDA_write_regs[RDA_REG_5] |=  RDA_VOL;          // set start volume
  RDA_writeAllRegs();                             // write all registers
  RDA_write_regs[RDA_REG_2] &= ~0x0002;           // clear soft reset
  RDA_writeReg(RDA_REG_2);                        // write to register 0x02
}
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
int main(void) { 
  // Setup
  _PROTECTED_WRITE(CLKCTRL.MCLKCTRLB, 7);         // set clock frequency to 1 MHz
  ADC_init();                                     // setup ADC
  OLED_init();                                    // setup OLED
  pinPullup(PIN_VOL_UP);                          // enable pullups for button pins
  pinPullup(PIN_VOL_DOWN);
  pinPullup(PIN_CH_UP);

  // Print start info
  OLED_clearScreen();
  OLED_println(HEADER);
  OLED_print("Starting ...");

  // Start the tuner
  RDA_init();
  if(EEPROM_get()) {
    RDA_setChannel(channel - 2); 
    RDA_waitTuning();
  }
  RDA_setVolume(volume);
  RDA_seekUp();
  RDA_waitTuning();

  // Loop
  while(1) {
    // Update information on OLED
    RDA_updateStatus();
    OLED_setCursor(0, 1);
    OLED_print("Station:  ");
    OLED_println(RDA_stationName);
    OLED_print("Vol: ");
    OLED_printVal(volume, 2, 0);
    OLED_print("   Frq: ");
    OLED_printVal(RDA_getFrequency(), 5, 2);
    OLED_print("Sig: ");
    OLED_printVal(RDA_signalStrength, 2, 0);
    OLED_print("   Bat: ");
    if(ADC_isWeak()) OLED_println("weak");
    else             OLED_println("OK");

    // Check CH+ button
    if(!pinRead(PIN_CH_UP)) {
      OLED_setCursor(0, 1);
      OLED_println("Tuning ...");
      OLED_clearLine(); OLED_clearLine();
      RDA_seekUp();
      RDA_waitTuning();
      EEPROM_update();
      while(!pinRead(PIN_CH_UP));
    }

    // Check VOL+ button
    if (!pinRead(PIN_VOL_UP)) {
      if (volume < 15) volume++;
      RDA_setVolume(volume);
      EEPROM_update();
      while(!pinRead(PIN_VOL_UP));
    }

    // Check VOL- button
    if (!pinRead(PIN_VOL_DOWN)) {
      if (volume) volume--;
      RDA_setVolume(volume);
      EEPROM_update();
      while(!pinRead(PIN_VOL_DOWN));
    }
  }
}
